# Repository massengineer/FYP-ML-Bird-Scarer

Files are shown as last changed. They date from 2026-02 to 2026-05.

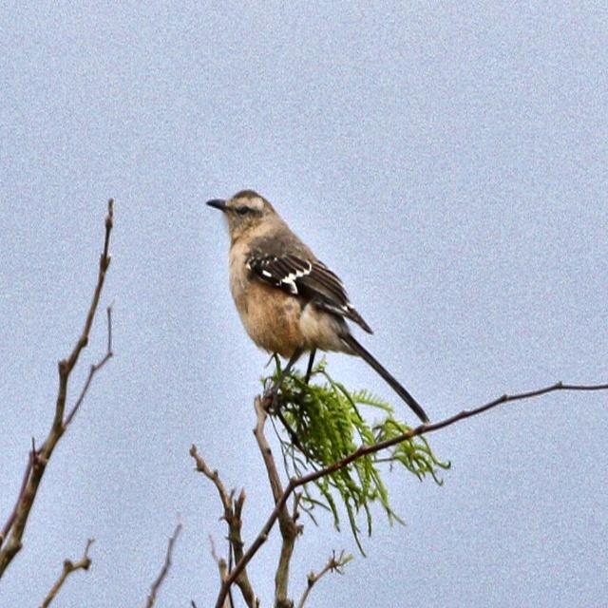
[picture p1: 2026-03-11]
fifth_model_validation_images/images/1492716d2916fd06_jpg.rf.b7eb82ddf107be1705cc3b7b00addbe3.jpg

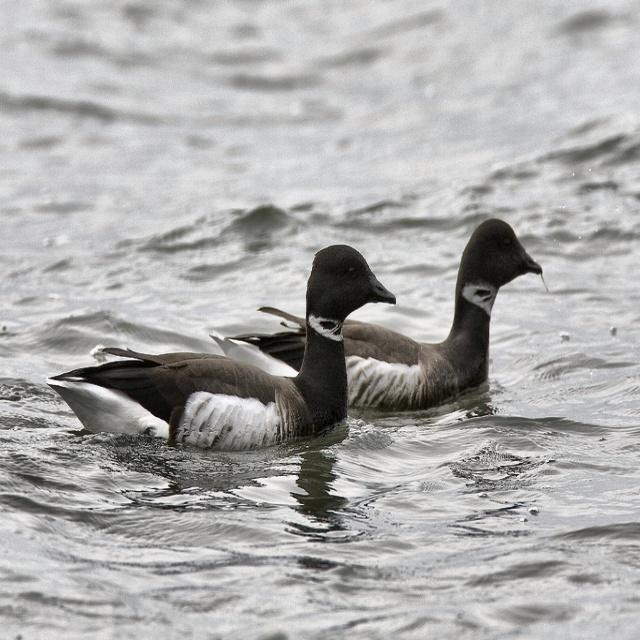
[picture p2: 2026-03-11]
fifth_model_validation_images/images/8af11f1227628c0c_jpg.rf.041cdeeb3d28e0580a33c0c5f7638376.jpg

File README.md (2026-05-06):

# Solar IoT Scarecrow: CNN Recognition with Multi-Modal Scaring Techniques

## Project Overview

This project is an automated bird deterrent system that uses machine learning (YOLOv8 object detection) to identify pest birds on the Raspberry Pi 5 and trigger multi-modal deterrent responses including audio playback (hawk screech sounds) and servo-based physical deterrents. The system is designed to be energy-efficient, responsive, and non-harmful to birds.

### Key Features
 - **Real-time Bird Detection**: YOLOv8 nano model optimised for Raspberry Pi 5
- **Multi-modal Deterrent**: Audio (hawk screech via Bluetooth speaker) + servo-based physical deterrent
- **PIR Motion Sensor Integration**: Reduces computational overhead by only processing frames when movement is detected
- **Video Recording**: Automatically records when birds are detected, with 5-second post-roll buffer
- **Hardware Optimisation**: Uses NCNN format models for faster inference on edge devices
- **Non-blocking Operations**: Asynchronous audio playback and Bluetooth connectivity management

--

## Lessons Learned & Future Directions

### Successful Strategies
1. **Iterative Model Development**: Six model versions allowed progressive performance improvement and optimisation
2. **NCNN Optimisation**: Critical for real-time Pi 5 inference
3. **Data Augmentation**: Significantly improved generalisation with comprehensive datasets
4. **Non-blocking Architecture**: Essential for responsive embedded systems
5. **Hardware Synchronisation**: Bluetooth audio trigger ensures coordinated multi-modal response

---

## Recommended Future Improvements
1. **Model Quantisation**: INT8 quantisation for further speedup
2. **Cloud Integration**: Remote monitoring and model updates
3. **Transfer Learning**: Fine-tune on domain-specific bird datasets

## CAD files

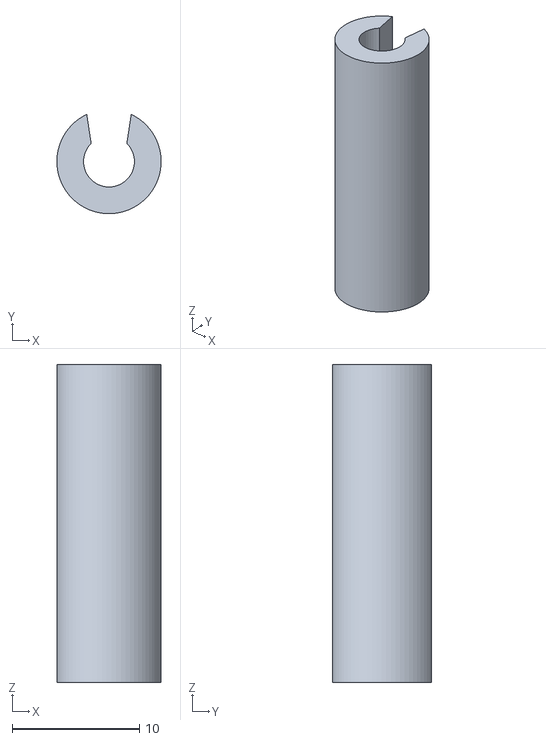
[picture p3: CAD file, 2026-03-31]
scaring_unit_cad/FYP Wire Gland Insert v2.stl
8.20 x 7.80 x 25.0

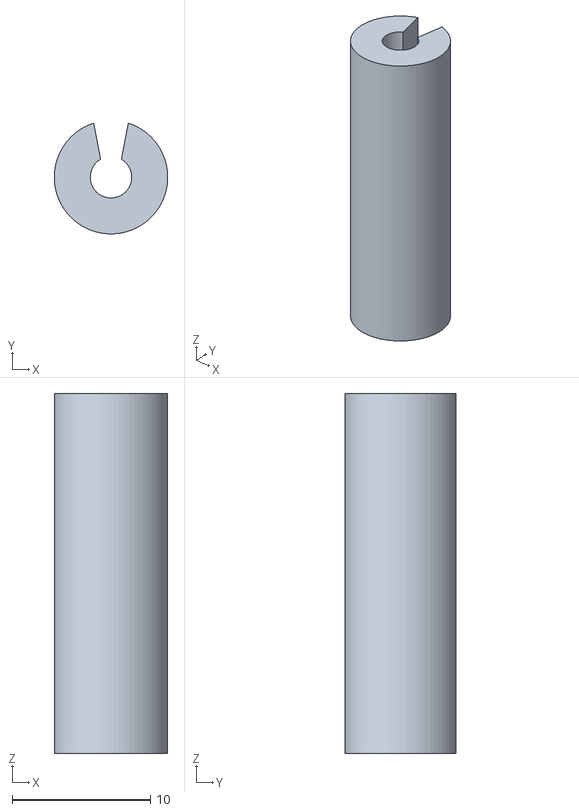
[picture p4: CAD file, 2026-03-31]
scaring_unit_cad/FYP Wire Gland Insert.stl
8.19 x 8.00 x 26.0

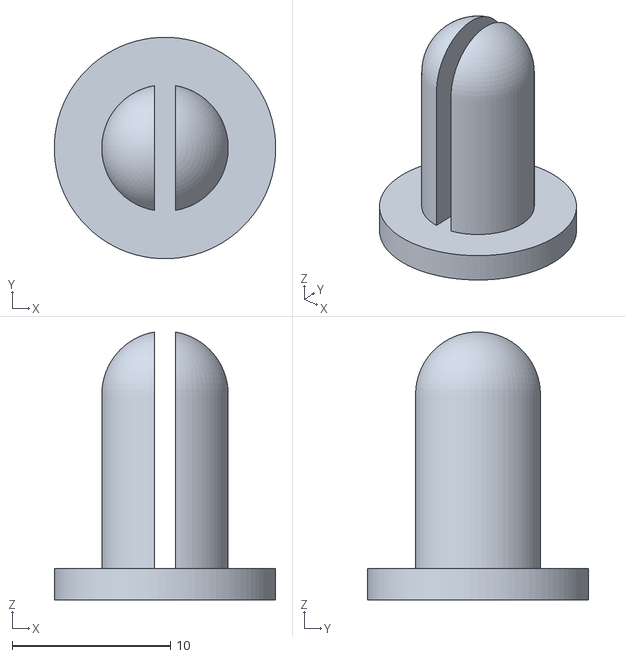
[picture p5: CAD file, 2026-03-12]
scaring_unit_cad/FYP CD Holder.stl
14.0 x 14.0 x 16.9

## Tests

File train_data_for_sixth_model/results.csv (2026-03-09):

epoch | time | train/box_loss | train/cls_loss | train/dfl_loss | metrics/precision(B) | metrics/recall(B) | metrics/mAP50(B) | metrics/mAP50-95(B) | val/box_loss | val/cls_loss | val/dfl_loss | lr/pg0 | lr/pg1 | lr/pg2
1 | 8.24663 | 0.76598 | 3.43267 | 1.10832 | 0.00349 | 0.8343 | 0.24871 | 0.1738 | 0.51827 | 3.14842 | 1.00988 | 0.00010003 | 0.00010003 | 0.00010003
2 | 13.0412 | 0.71077 | 2.82271 | 1.10803 | 0.00358 | 0.81426 | 0.30561 | 0.21947 | 0.76749 | 3.04733 | 1.28882 | 0.000212935 | 0.000212935 | 0.000212935
3 | 18.0443 | 0.75886 | 2.35708 | 1.09684 | 0.00367 | 0.8761 | 0.34248 | 0.25424 | 0.71128 | 2.84755 | 1.23805 | 0.000324332 | 0.000324332 | 0.000324332
4 | 23.3648 | 0.72787 | 2.12892 | 1.04533 | 0.06242 | 0.80276 | 0.42302 | 0.27459 | 0.90188 | 2.82334 | 1.41661 | 0.000434219 | 0.000434219 | 0.000434219
5 | 28.5131 | 0.73839 | 1.94332 | 1.05104 | 0.77462 | 0.18446 | 0.45774 | 0.31166 | 1.1421 | 2.82383 | 1.77244 | 0.000542597 | 0.000542597 | 0.000542597
6 | 33.1411 | 0.83125 | 1.8447 | 1.12757 | 0.78552 | 0.16669 | 0.30625 | 0.18485 | 1.22624 | 3.07672 | 2.06071 | 0.000649466 | 0.000649466 | 0.000649466
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

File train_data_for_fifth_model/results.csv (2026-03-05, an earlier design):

epoch | time | train/box_loss | train/cls_loss | train/dfl_loss | metrics/precision(B) | metrics/recall(B) | metrics/mAP50(B) | metrics/mAP50-95(B) | val/box_loss | val/cls_loss | val/dfl_loss | lr/pg0 | lr/pg1 | lr/pg2
1 | 9.52993 | 0.87652 | 3.36791 | 1.1602 | 0.00465 | 0.79578 | 0.19424 | 0.14796 | 0.56515 | 3.18239 | 1.0517 | 0.00011432 | 0.00011432 | 0.00011432
2 | 13.8497 | 0.79855 | 2.75589 | 1.10841 | 0.00427 | 0.77217 | 0.26767 | 0.1903 | 0.88408 | 3.09974 | 1.31958 | 0.000241327 | 0.000241327 | 0.000241327
3 | 19.1699 | 0.81981 | 2.32528 | 1.09787 | 0.6537 | 0.17118 | 0.35825 | 0.23847 | 0.9051 | 2.9916 | 1.40577 | 0.000366636 | 0.000366636 | 0.000366636
4 | 24.6678 | 0.87512 | 2.11147 | 1.10541 | 0.94454 | 0.04264 | 0.32491 | 0.1825 | 1.1185 | 3.05751 | 1.69322 | 0.000490247 | 0.000490247 | 0.000490247
5 | 29.5335 | 0.89237 | 1.94294 | 1.10844 | 0.5481 | 0.19169 | 0.33054 | 0.17799 | 1.16599 | 3.12064 | 1.67502 | 0.000612161 | 0.000612161 | 0.000612161
6 | 35.043 | 0.91889 | 1.96102 | 1.13227 | 0.69014 | 0.06846 | 0.20764 | 0.10492 | 1.46155 | 3.21587 | 2.18867 | 0.000732377 | 0.000732377 | 0.000732377
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

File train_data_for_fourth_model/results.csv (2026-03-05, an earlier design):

epoch | time | train/box_loss | train/cls_loss | train/dfl_loss | metrics/precision(B) | metrics/recall(B) | metrics/mAP50(B) | metrics/mAP50-95(B) | val/box_loss | val/cls_loss | val/dfl_loss | lr/pg0 | lr/pg1 | lr/pg2
1 | 9.16051 | 1.09969 | 3.46756 | 1.29602 | 0.00527 | 0.75907 | 0.24032 | 0.16519 | 0.62658 | 3.12216 | 1.08089 | 0.00011432 | 0.00011432 | 0.00011432
2 | 13.5204 | 1.108 | 2.90171 | 1.28468 | 0.00522 | 0.8332 | 0.28705 | 0.20275 | 0.75815 | 3.03712 | 1.17529 | 0.000241727 | 0.000241727 | 0.000241727
3 | 18.7719 | 1.0705 | 2.39946 | 1.28447 | 0.00439 | 0.71802 | 0.17594 | 0.12325 | 1.07834 | 3.15737 | 1.43957 | 0.000367862 | 0.000367862 | 0.000367862
4 | 23.5678 | 1.02047 | 2.23753 | 1.23973 | 0.41763 | 0.28316 | 0.28823 | 0.19652 | 1.08887 | 3.02777 | 1.59259 | 0.000492723 | 0.000492723 | 0.000492723
5 | 28.5786 | 1.14579 | 2.14859 | 1.30957 | 0.60535 | 0.05006 | 0.20826 | 0.11813 | 1.25407 | 3.01816 | 1.80516 | 0.000616311 | 0.000616311 | 0.000616311
6 | 34.0564 | 1.15181 | 2.08148 | 1.27343 | 0.56941 | 0.0731 | 0.1971 | 0.11779 | 1.44095 | 2.97848 | 1.9225 | 0.000738625 | 0.000738625 | 0.000738625
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

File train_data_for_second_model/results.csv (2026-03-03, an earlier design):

epoch | time | train/box_loss | train/cls_loss | train/dfl_loss | metrics/precision(B) | metrics/recall(B) | metrics/mAP50(B) | metrics/mAP50-95(B) | val/box_loss | val/cls_loss | val/dfl_loss | lr/pg0 | lr/pg1 | lr/pg2
1 | 23.2503 | 1.36885 | 2.90899 | 1.37589 | 0.05677 | 0.10577 | 0.04701 | 0.02028 | 1.5922 | 3.58178 | 2.02836 | 0.000469224 | 0.000469224 | 0.000469224
2 | 42.0035 | 1.42422 | 2.52042 | 1.42476 | 0.40844 | 0.08176 | 0.06929 | 0.04123 | 2.00636 | 3.32352 | 2.33962 | 0.000940877 | 0.000940877 | 0.000940877
3 | 61.64 | 1.55918 | 2.54724 | 1.55744 | 0.22802 | 0.36091 | 0.15343 | 0.07697 | 2.13427 | 12.2122 | 2.89574 | 0.00140781 | 0.00140781 | 0.00140781
4 | 79.9022 | 1.63537 | 2.32642 | 1.5678 | 0.4458 | 0.2113 | 0.19239 | 0.13761 | 2.19892 | 4.05748 | 2.26312 | 0.00140778 | 0.00140778 | 0.00140778
5 | 99.5458 | 1.52499 | 2.18921 | 1.50981 | 0.7952 | 0.10692 | 0.11731 | 0.05737 | 2.0006 | 5.8527 | 2.2096 | 0.00140071 | 0.00140071 | 0.00140071
6 | 117.673 | 1.4781 | 2.11517 | 1.47909 | 0.1762 | 0.21514 | 0.13484 | 0.06876 | 1.90149 | 3.52405 | 2.04537 | 0.00139363 | 0.00139363 | 0.00139363
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

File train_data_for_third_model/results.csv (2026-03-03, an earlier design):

epoch | time | train/box_loss | train/cls_loss | train/dfl_loss | metrics/precision(B) | metrics/recall(B) | metrics/mAP50(B) | metrics/mAP50-95(B) | val/box_loss | val/cls_loss | val/dfl_loss | lr/pg0 | lr/pg1 | lr/pg2
1 | 23.944 | 1.04355 | 2.86737 | 1.22065 | 0.65785 | 0.13229 | 0.21309 | 0.15545 | 0.89187 | 3.17851 | 1.03969 | 0.000469624 | 0.000469624 | 0.000469624
2 | 44.9827 | 1.21169 | 2.40539 | 1.3086 | 0.48996 | 0.28279 | 0.1896 | 0.10846 | 1.1223 | 4.16405 | 1.31595 | 0.000941275 | 0.000941275 | 0.000941275
3 | 67.5074 | 1.27611 | 2.26464 | 1.31458 | 0.71311 | 0.22342 | 0.11993 | 0.04905 | 1.26629 | 9.99762 | 1.58817 | 0.00140821 | 0.00140821 | 0.00140821
4 | 88.6388 | 1.256 | 2.20201 | 1.36274 | 0.20343 | 0.39147 | 0.2167 | 0.1283 | 1.29567 | 5.3712 | 1.51557 | 0.00140778 | 0.00140778 | 0.00140778
5 | 110.647 | 1.22988 | 2.0783 | 1.34609 | 0.27352 | 0.43501 | 0.3486 | 0.18121 | 1.10115 | 3.84215 | 1.2787 | 0.00140071 | 0.00140071 | 0.00140071
6 | 131.417 | 1.25569 | 1.95177 | 1.34617 | 0.22322 | 0.44836 | 0.26202 | 0.13577 | 1.16562 | 4.1265 | 1.31764 | 0.00139363 | 0.00139363 | 0.00139363
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

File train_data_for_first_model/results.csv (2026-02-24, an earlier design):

epoch | time | train/box_loss | train/cls_loss | train/dfl_loss | metrics/precision(B) | metrics/recall(B) | metrics/mAP50(B) | metrics/mAP50-95(B) | val/box_loss | val/cls_loss | val/dfl_loss | lr/pg0 | lr/pg1 | lr/pg2
1 | 5.17597 | 2.77821 | 4.46978 | 1.62324 | 0.00182 | 0.04 | 0.0016 | 0.00032 | 1.67523 | 4.3902 | 1.15811 | 8e-05 | 8e-05 | 8e-05
2 | 6.34027 | 2.24679 | 4.38112 | 1.42135 | 0 | 0 | 0 | 0 | 1.67721 | 4.264 | 1.12931 | 0.000167195 | 0.000167195 | 0.000167195
3 | 7.40037 | 2.19912 | 4.20748 | 1.37374 | 0.00192 | 0.2 | 0.00524 | 0.00157 | 1.52992 | 4.17324 | 1.07021 | 0.00025142 | 0.00025142 | 0.00025142
4 | 8.46338 | 2.0119 | 3.95595 | 1.28879 | 0.00718 | 0.32 | 0.01088 | 0.00594 | 1.66867 | 4.02857 | 1.12551 | 0.000332675 | 0.000332675 | 0.000332675
5 | 9.54266 | 2.22553 | 3.70542 | 1.32135 | 0.0069 | 0.2 | 0.168 | 0.1355 | 1.77539 | 3.5633 | 1.1677 | 0.00041096 | 0.00041096 | 0.00041096
6 | 11.0791 | 2.05988 | 3.38662 | 1.22622 | 1 | 0.10696 | 0.17006 | 0.10965 | 2.04128 | 3.21905 | 1.23865 | 0.000486275 | 0.000486275 | 0.000486275
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

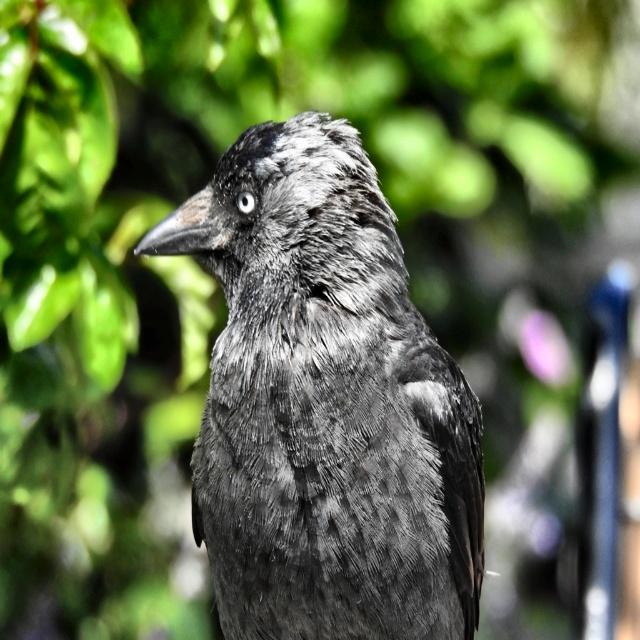
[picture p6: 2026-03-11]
fifth_model_validation_images/images/dfc5a4b74ed26282_jpg.rf.ca2303febdbc76299b01e18eafeecf0b.jpg

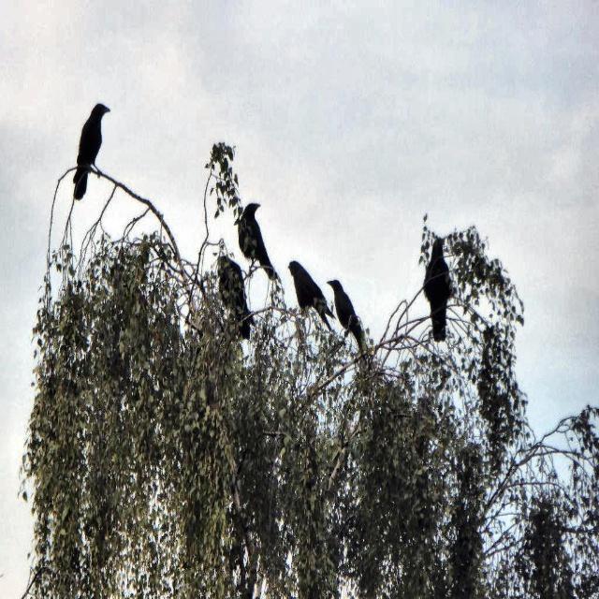
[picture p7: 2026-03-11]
fifth_model_validation_images/images/4c3cf53778d8954f_jpg.rf.ba966dd472d4c414749a840dfc9f231f.jpg

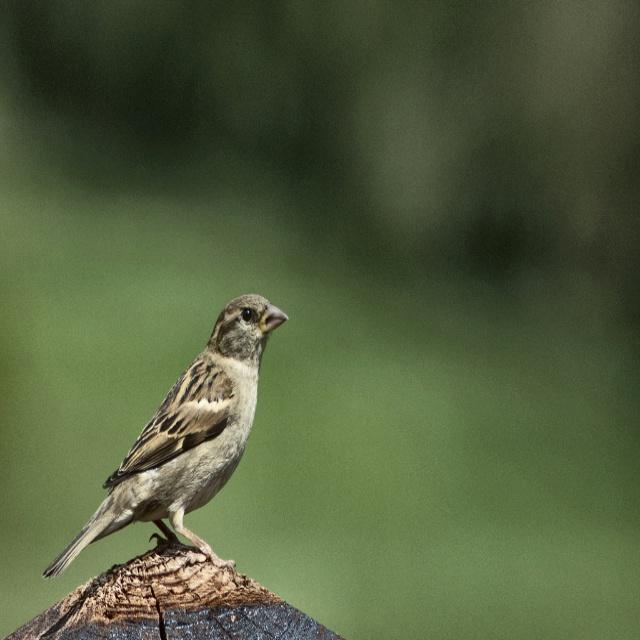
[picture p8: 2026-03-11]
fifth_model_validation_images/images/b2da9c94cbdea620_jpg.rf.bc916620fd242293c58dd9b87eb204f6.jpg

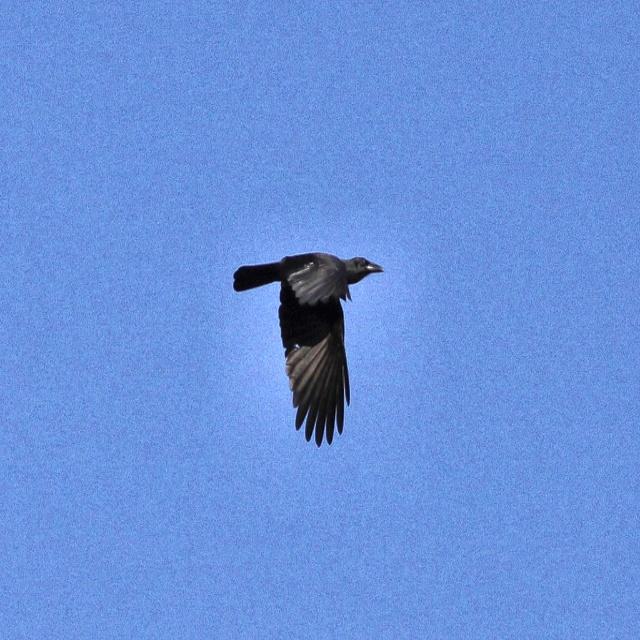
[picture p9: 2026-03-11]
fifth_model_validation_images/images/7d0bd1eaec068597_jpg.rf.3eb17b3c61c7fef28e48dbc8b4ebdf9f.jpg

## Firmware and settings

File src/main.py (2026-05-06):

import os
import time
import subprocess
import RPi.GPIO as GPIO
from datetime import datetime
from picamera2 import Picamera2
from picamera2.encoders import H264Encoder
from libcamera import controls
from bird_recognition import MLBirdClassifier
import cv2
import numpy as np

# Import necessary functions from dotenv library
from dotenv import load_dotenv

# Load variables from .env file
load_dotenv()

# Hardware Setup
GPIO.setmode(GPIO.BCM)
BCM4 = 4
GPIO.setup(BCM4, GPIO.IN)


class CameraRecorder:
    def __init__(self):
        self.picam2 = Picamera2()
        config = self.picam2.create_video_configuration(
            main={"size": (1280, 720), "format": "RGB888"}
        )
        self.picam2.configure(config)
        # Define encoder once to prevent resource leaks
        self.encoder = H264Encoder(10000000)
        self.picam2.start()
        self.picam2.set_controls({"AfMode": controls.AfModeEnum.Continuous})

        self.classifier = MLBirdClassifier()
        # CLAHE to match preprocessing pipeline (applied to camera frames before inference)
        self.clahe = cv2.createCLAHE(clipLimit=2.0, tileGridSize=(8, 8))
        self.recording = False
        self.output_dir = "/home/dys/pi/recordings"
        if not os.path.exists(self.output_dir):
            os.makedirs(self.output_dir)

    def start_recording(self):
        if not self.recording:
            timestamp = datetime.now().strftime("%Y%m%d_%H%M%S")
            filename = f"{self.output_dir}/recording_{timestamp}.h264"
            try:
                # Non-blocking start
                self.picam2.start_recording(self.encoder, filename)
                self.recording = True
                print(f"Recording started: {filename}")
            except Exception as e:
                print(f"Recording failed: {e}")

    def stop_recording(self):
        if self.recording:
            try:
                self.picam2.stop_recording()
                self.picam2.start()
                print("Recording stopped - Camera stream resumed for AI")
            except Exception as e:
                print(f"Failed to stop recording: {e}")
            self.recording = False


def play_hawk_screech(file_path):
    """Triggers audio without freezing the main script."""
    print(f"Triggering audio: {file_path}")
    try:
        # Set volume in background
        os.system("pactl set-sink-volume @DEFAULT_SINK@ 100% &")
        # Popen is non-blocking (the script keeps running while music plays)
        subprocess.Popen(["paplay", file_path])
    except Exception as e:
        print(f"Audio Error: {e}")


def is_bluetooth_connected():
    result = subprocess.run(
        ["pactl", "list", "short", "sinks"], capture_output=True, text=True
    )
    return "bluez_output" in result.stdout


def main():
    recorder = CameraRecorder()
    last_motion_time = 0
    audio_cooldown = 15
    last_audio_time = 0
    stop_delay = 5  # Keeps recording for 5 seconds after the bird leaves

    print("Sensor camera recording system activated...")
    print("Press Ctrl+C to exit")

    try:
        while True:
            now = time.time()
            movement_detected = GPIO.input(BCM4)

            if movement_detected:
                # 1. Update the motion timer every time the PIR is high
                last_motion_time = now

                # 2. Start recording immediately if not already recording
                if not recorder.recording:
                    recorder.start_recording()

                # 3. AI Scan (Does not affect the recording duration)
                frame = recorder.picam2.capture_array()
                # Apply CLAHE preprocessing to match training conditions (improves detection accuracy)
                try:
                    img = frame
                    if img.dtype != np.uint8:
                        img = (img * 255).astype(np.uint8)
                    lab = cv2.cvtColor(img, cv2.COLOR_RGB2LAB)
                    L, a, b = cv2.split(lab)
                    L = recorder.clahe.apply(L)
                    lab = cv2.merge((L, a, b))
                    proc_frame = cv2.cvtColor(lab, cv2.COLOR_LAB2RGB)
                except Exception:
                    proc_frame = frame
                # UNPACKING: (is_bird: bool, annotated_frame, target_flags: list[bool])
                is_bird, annotated_frame, target_flags = recorder.classifier.scan_frame(
                    proc_frame
                )

                # Prioritise raven (index 0) over sparrow (index 1).
                if is_bird:
                    # Raven
                    if target_flags and target_flags[0]:
                        if (now - last_audio_time) > audio_cooldown:
                            if is_bluetooth_connected():
                                play_hawk_screech(
                                    "/home/dys/pi/FYP-ML-Bird-Scarer/audio_samples/528625__justinamolsch__hawk-screech.wav"
                                )
                                last_audio_time = now
                            else:
                                print("ESP32 missing! Reconnecting...")
                                subprocess.Popen(
                                    [
                                        "bluetoothctl",
                                        "connect",
                                        os.getenv("ESP32_MAC_ADDRESS"),
                                    ]
                                )

                    # Sparrow (only if raven wasn't triggered)
                    elif target_flags and len(target_flags) > 1 and target_flags[1]:
                        if (now - last_audio_time) > audio_cooldown:
                            if is_bluetooth_connected():
                                play_hawk_screech(
                                    "/home/dys/pi/FYP-ML-Bird-Scarer/audio_samples/chipingsparrow.wav"
                                )
                                last_audio_time = now
                            else:
                                print("ESP32 missing! Reconnecting...")
                                subprocess.Popen(
                                    [
                                        "bluetoothctl",
                                        "connect",
                                        os.getenv("ESP32_MAC_ADDRESS"),
                                    ]
                                )

                    else:
                        print(
                            "PIR High! Movement detected (Animal/Other), recording in progress..."
                        )
                else:
                    print(
                        "PIR High! Movement detected (Animal/Other), recording in progress..."
                    )

            # Persistent Stop Logic

            # This runs every loop, even if movement_detected is False
            if recorder.recording:
                if (now - last_motion_time) > stop_delay:
                    print(f"No bird for {stop_delay}s. Stopping.")
                    recorder.stop_recording()

            time.sleep(0.1)  # Faster loop for smoother logic

    except KeyboardInterrupt:
        print("\nProgram interrupted...")
    finally:
        if recorder.recording:
            recorder.stop_recording()
        GPIO.cleanup()
        print("System shutdown")


if __name__ == "__main__":
    main()

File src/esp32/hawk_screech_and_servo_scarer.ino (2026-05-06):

#include "AudioTools.h"
#include "BluetoothA2DPSink.h"
#include <ESP32Servo.h>

I2SStream i2s;
BluetoothA2DPSink a2dp_sink(i2s);

Servo myservo;
int servoPin = 4;

// Volatile flag
volatile bool triggerServo = false;

void audio_state_changed(esp_a2d_audio_state_t state, void *ptr) {
  // Set the flag here
  if (state == ESP_A2D_AUDIO_STATE_STARTED) {
    triggerServo = true; 
  }
}

void setup() {
    Serial.begin(115200);

    auto cfg = i2s.defaultConfig();
    cfg.pin_bck = 26;
    cfg.pin_ws = 25;
    cfg.pin_data = 22;
    i2s.begin(cfg);

    myservo.setPeriodHertz(50);
//    // Initial test movement
//    myservo.attach(servoPin);
//    myservo.write(0); 
//    delay(500);
//    myservo.detach();
  
    // Register the callback
    a2dp_sink.set_on_audio_state_changed(audio_state_changed);
    a2dp_sink.start("Hawk_Speaker");
}

void loop() {
  // Check if the Bluetooth callback set the flag to true
  if (triggerServo) {

    for (int i = 0; i < 3; i++) {
      myservo.attach(servoPin);
      myservo.write(90); 
      delay(500);
      myservo.write(0);  
      delay(500);
      myservo.detach();
      }
    
    
    triggerServo = false; // Reset the flag
  }
}

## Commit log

2026-02-13 main: created environment variable file to store MAC address in and added .env to the .gitignore file. I have also shuffled aroudn the logic to start merging it with the pre-existing camera recording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
2026-02-13 main: managed to clean up some import errors and added some audio cooldown logic to stop overplaying the audio sample.
    [bird_recognition.py, main.py]
2026-02-13 feat/ml-recognition: I have successfully got the code to work and recognise a bird specifically and filter out humans and objects and only record a video when the confidence is more than 50%. It then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
2026-02-13 feat/ml-recognition: I have now got the script to detect a bird with AI and produce a sound with the ESP32 bluetooth speaker. The thing that I need to fix is that when a bird has not been detected fo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
    [main.py]
2026-02-18 main: updated audio sample's path to an absolute path.
2026-02-18 main: added indent to else statement to see if it helps with the order of the logic to stop the sccript from jamming and pausing further scans for birds.
    [main.py]
2026-02-18 main: updated flow of logic to make sure that there are non-blocking processes by using Popen.
2026-02-18 main: restored some old code without hard resetting the branch.
    [main.py]
2026-02-18 main: all logic works when running script without service and resumes recording and only recognises bird and is not only triggered when PIR sensor goes high.
2026-02-24 main: added newly trained and int8 ncnn quantised model that differentiates between different pest bird species and ducks. I have updated the code to look at the correct model now. IDs have been adde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
    [model.ncnn.param, results.csv]
2026-02-28 feat/esp32-acousto-mechanics: This code is used on an exterior esp-WROOM-32 board to play audio through a speaker driven by a class D amplifier and a servo motor.
2026-02-28 main: moved the esp32 logic into the src folder and added more information to the README file for later reference.
2026-02-28 feat/esp32-acousto-mechanics: tried to fix merge issues and add env variable for MAC address.
2026-02-28 main: recuperated lost bird_recognition script after some strange rebase/ merge issue.
    [bird_recognition.py]
2026-02-28 main: recuperated lost test_recognition script after some strange rebase/ merge issue.
    [test_recognition.py]
2026-03-03 main: added model training data, preprocessing python script that scraped images from open images v7 dataset, and organised files into appropriate locations.
    [results.csv]
2026-03-03 main: added verfication script to check what classes are in the data.yaml files for each best.pt model. Added these class IDs to the bird recognition script but it still is not working properly.
    [model.ncnn.param]
2026-03-04 main: tried to rearrange logic which triggers recording separately from the recognition logic, however, the recording are way too short because the logic is still semi-tied into the recogniton logic 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
    [main.py]
2026-03-05 main: added newly trained and most accurate models. Tested the livefeed to get human verfication, not just from empirical data/ results. Organised files and models.
    [model.ncnn.param, results.csv]
2026-03-09 main: added sixth model and its relative training data to the project. This model most likely will not be deployed in production.
    [results.csv]
2026-03-10 Revise README for project details, updated title, and consistency.
    Updated project title and various sections for consistency and clarity. Changed references from PiCamera2 to PiCamera3 and updated servo model from MG90S to MG995. Adjusted image size parameters and 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
2026-03-11 main: created a live average reading and final output metrics functionality to the test recognition script to measure inference on the Raspberry Pi 5. Add a test for singular static images to predict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
2026-03-12 main: added .stl file for the servo CD mount.
    [FYP CD Holder.stl]
2026-03-12 main: added yolo datasets from PC used for training and data collation. I have organised the files too.
    [FYP CD Holder.stl]
2026-04-09 main: added CLAHE preprocessing to live frames to match that of the dataset the model was trained on. This should increase confidence in settings with less than optimal lighting.
